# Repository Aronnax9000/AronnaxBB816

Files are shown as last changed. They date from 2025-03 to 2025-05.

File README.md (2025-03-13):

# AronnaxBB816
Memory Board
16777216 bytes = 16 MB = 0x1000000
65536 bytes = 64 KB 0x10000 (0x0000 - 0xFFFF)
There are sixteen 64 KB banks in a megabyte.
2^20 1 megabyte 0x100000 

0x000000-0x07FFFF Low  512 KB RAM
0x080000-0x0FFFFF High 512 KB RAM
0x000100-0x0001FF Bank 0 Page 1 I/O
                  VIA 0 (16 bytes)
                  VIA 1 (16 bytes)
                  ACIA (4 bytes)
                  
0x008000-0x00FFFF EEPROM (read when E signal is active)
                  RAM (write always on ~WR, read when E signal is not active)

Board uses A0-A19 (20 lines). 

Active when MEG0 = ~A23 * ~A22 * ~A21 * ~A20.
MEG0_UPPER = MEG0 * A19
MEG0_LOWER = MEG0 * ~A19

~BANK0_UPPER = ~BANK0 + ~A15
~BANK0_LOWER = ~BANK0 + A15

~EEPROM_CS = ~E + ~BANK0_UPPER

I/O Active when BANK0_LOWER * A8 * ~A9 * ~A10 * ~A11 * ~A12 * ~A13 * ~A14

Vector Pull Rewrite

2.28 Vector Pull (VPB)

The Vector Pull active low output indicates that a vector location is being addressed during an interrupt
sequence. VPB is low during the last two interrupt sequence cycles, during which time the processor loads
the PC with the interrupt handler vector location. The VPB signal may be used to select and prioritize
interrupts from several sources by modifying the vector addresses.

Table 5-2 Emulation Mode Vector Locations (8-bit Mode)

|Address | Label | Function | 
00FFFE,F | IRQB/BRK | Hardware/Software | 
00FFFC,D | RESETB | Hardware | 
00FFFA,B | NMIB | Hardware | 
00FFF8,9 | ABORTB | | Hardware | 
00FFF6,7 | (Reserved) | Hardware | 
00FFF4,5 | COP | Software | 
00FFF2,3 | (Reserved) | 
00FFF0,1 | (Reserved) | 

Table 5-3 Native Mode Vector Locations (16-bit Mode)

Address | Label | Function | 
00FFEE,F | IRQB | Hardware | 
00FFEC,D | (Reserved) | 
00FFEA,B | NMIB | Hardware | 
00FFE8,9 | ABORTB| | 
00FFE6,7 | BRK | Software | 
00FFE4,5 | COP | Software| 
00FFE2,3 | (Reserved) | |
00FFE0,1 | (Reserved) | |

The VP output is low during the two cycles used for vector location access. When an interrupt is executed,
D=0 and I=1 in Status Register P.

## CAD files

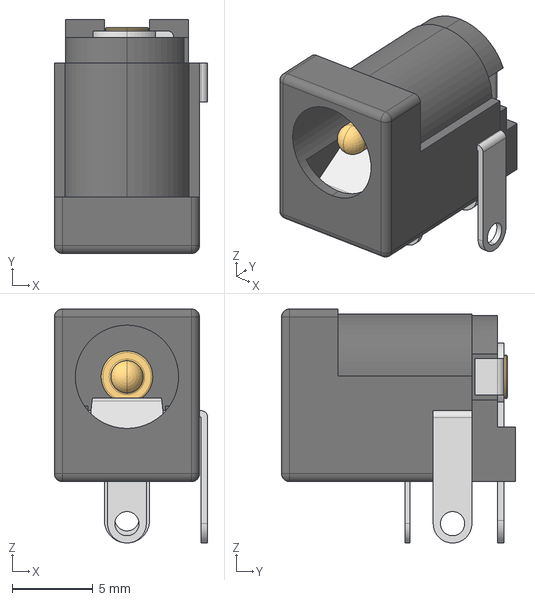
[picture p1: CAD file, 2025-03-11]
AronnaxMemory/3dmodels/163-179PH-EX.stp
9.50 x 14.5 x 14.5 mm

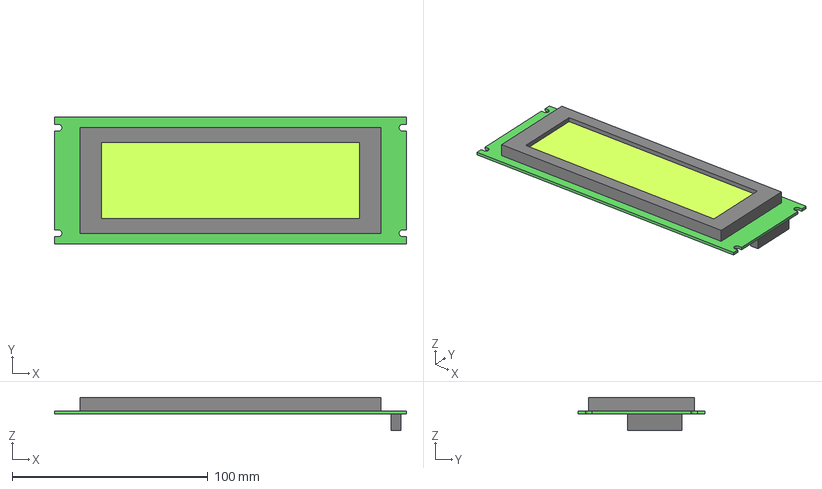
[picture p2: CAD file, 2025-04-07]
AronnaxMemory/3dmodels/lcd24064.step
180.0 x 65.0 x 17.1 mm
PCBBody
ConnBody
Matrix
Display

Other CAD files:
AronnaxMemory/3dmodels/lcd24064.FCStd
AronnaxMemory/3dmodels/lcd24064.stl

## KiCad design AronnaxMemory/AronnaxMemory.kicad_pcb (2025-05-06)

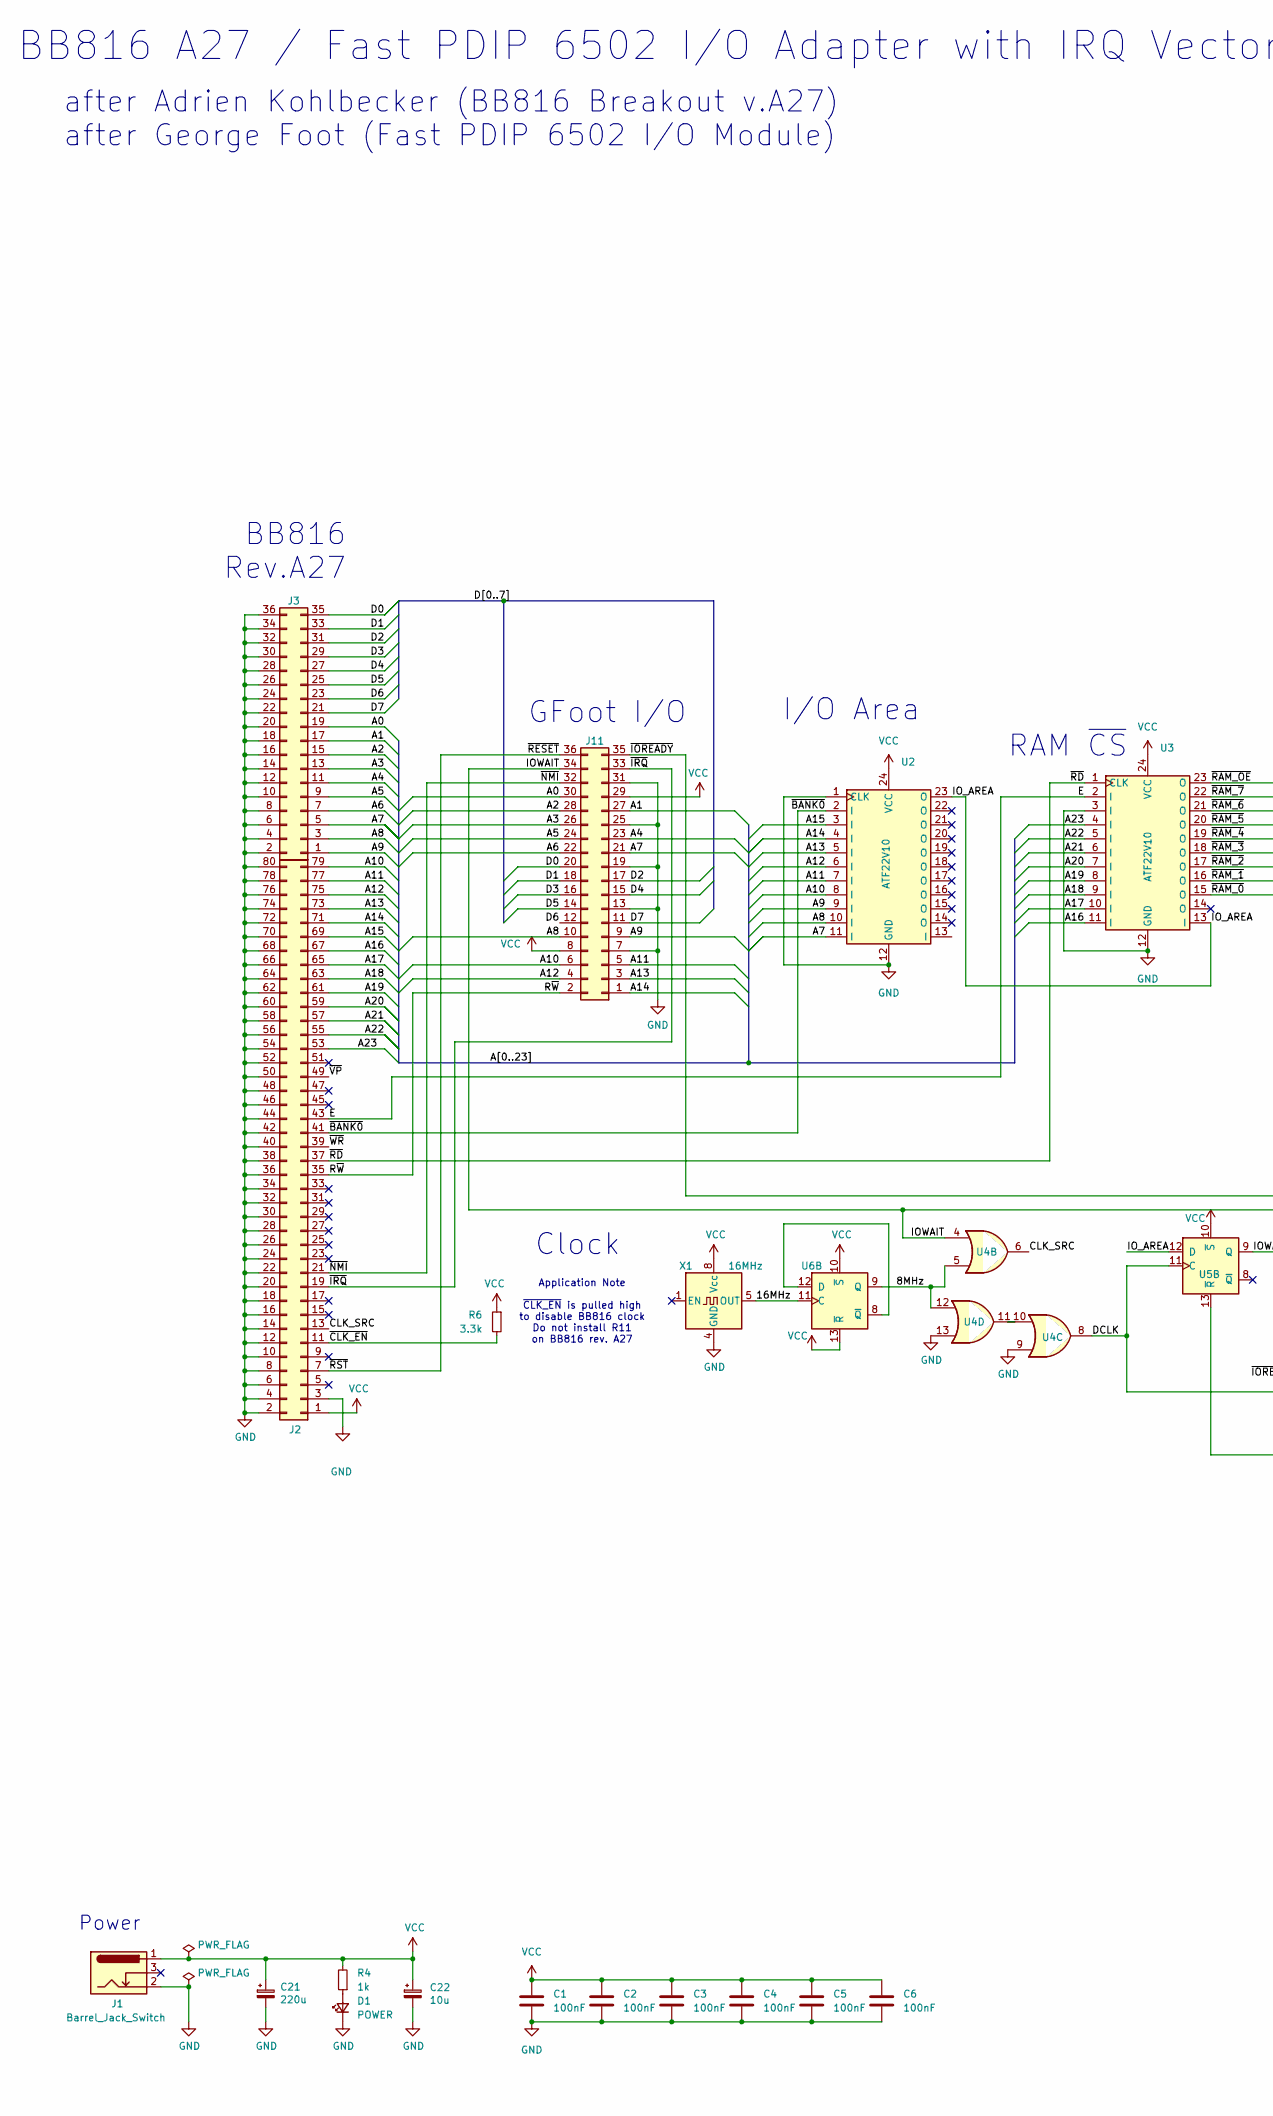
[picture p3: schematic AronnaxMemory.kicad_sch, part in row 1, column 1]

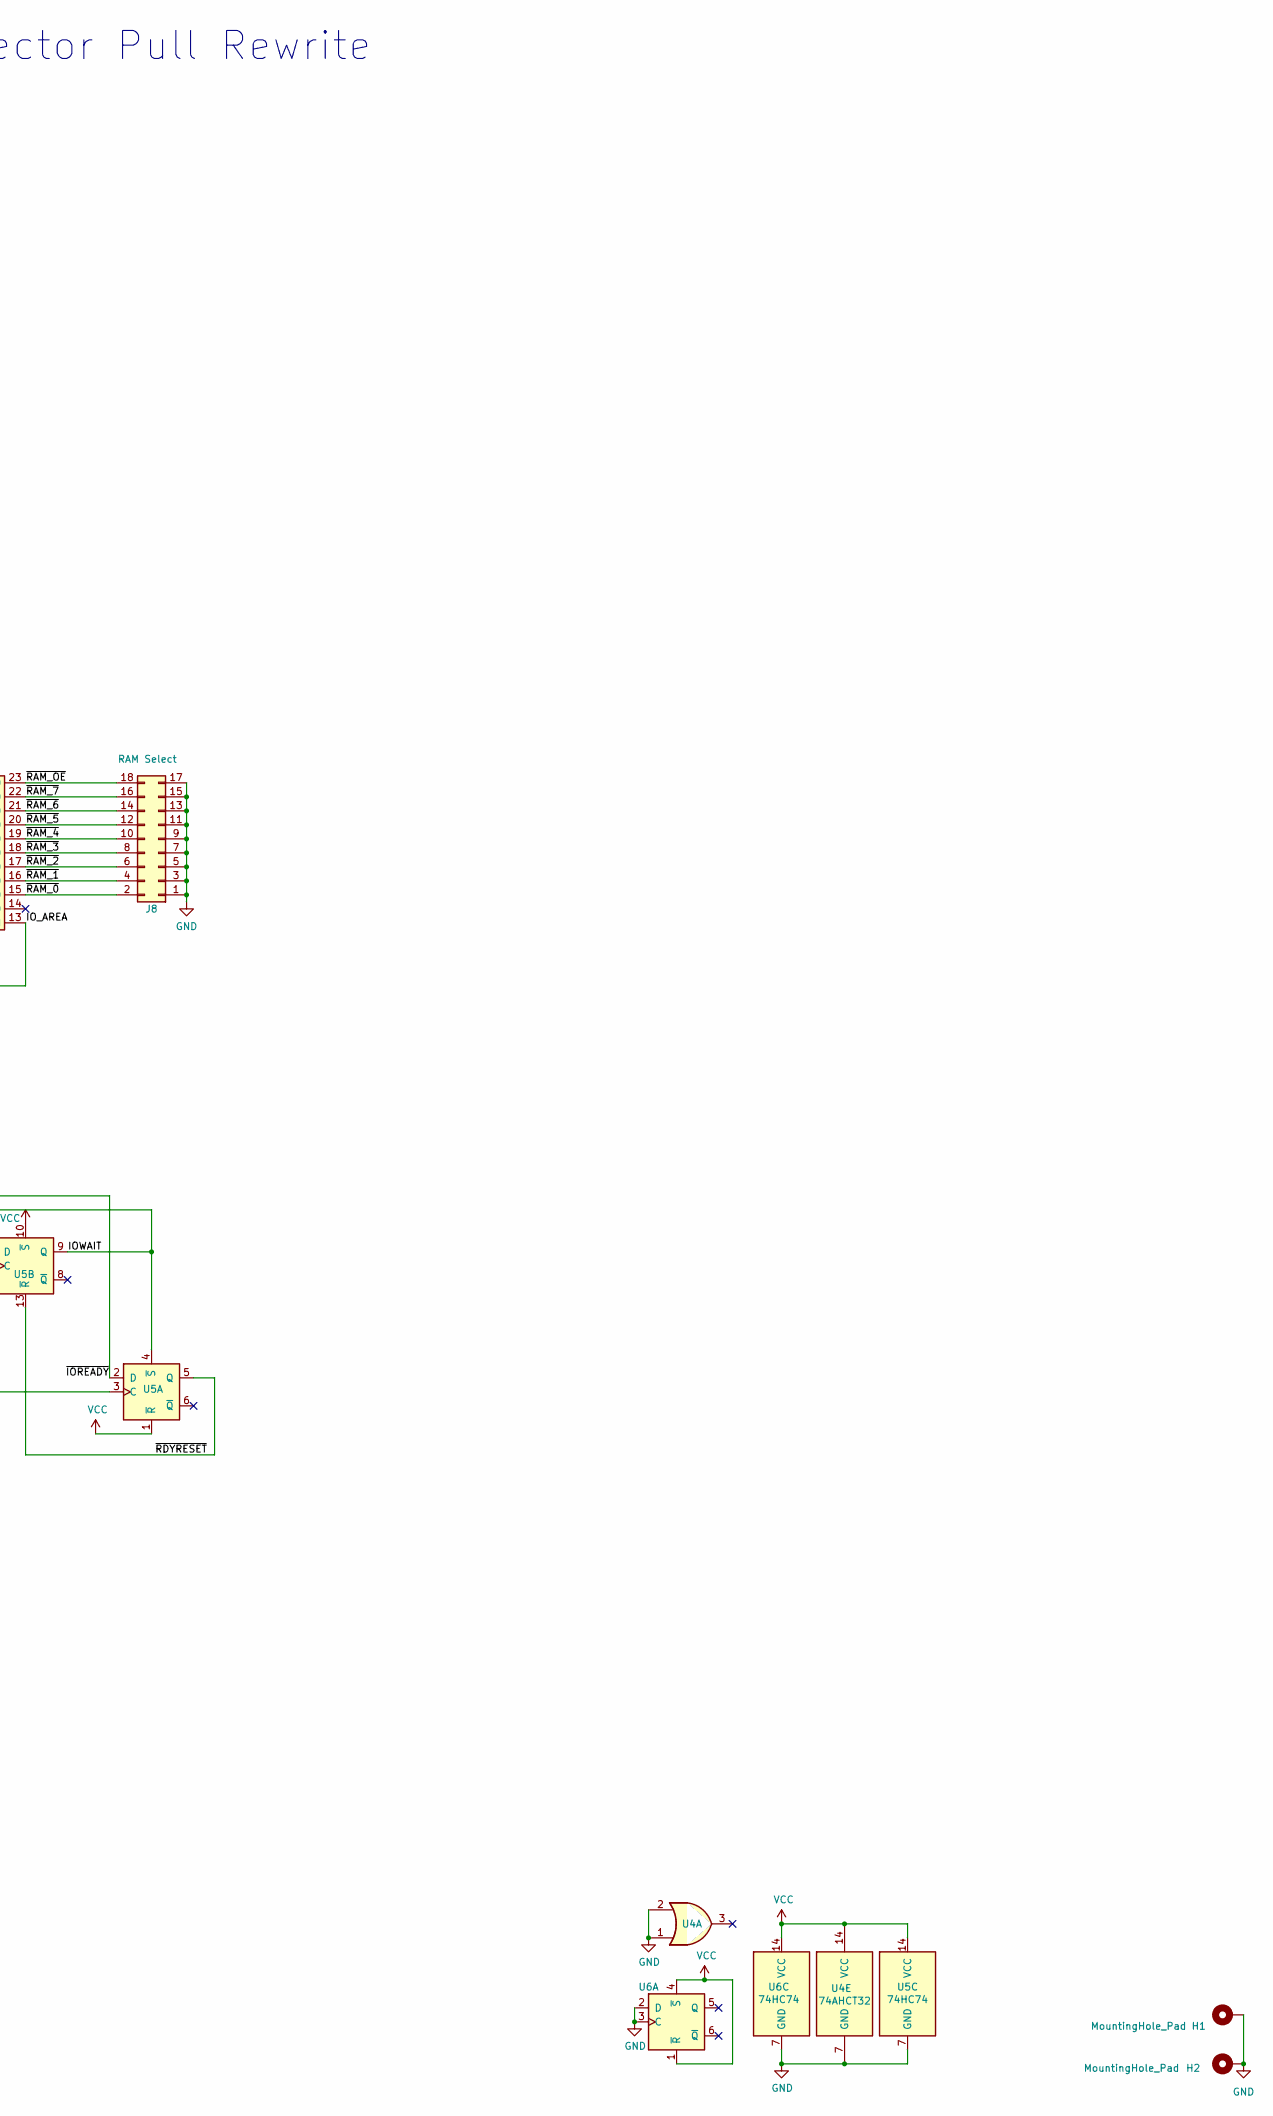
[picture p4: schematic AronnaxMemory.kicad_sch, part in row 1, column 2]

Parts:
C1, C2, C3, C4, C5, C6: 100nF; C_Disc_D3.4mm_W2.1mm_P2.50mm
C21: 220u; CP_Radial_D6.3mm_P2.50mm
C22: 10u; CP_Radial_D4.0mm_P1.50mm
D1: POWER; LED_D3.0mm
H1, H2: MountingHole_Pad; MountingHole_3.2mm_M3_Pad
J1: Barrel_Jack_Switch; BarrelJack_Horizontal
J2: Conn_02x40_Odd_Even; PinHeader_2x40_P2.54mm_Vertical
J3: Conn_02x18_Odd_Even; PinHeader_2x18_P2.54mm_Vertical
J8: RAM Select; PinHeader_2x09_P2.54mm_Vertical
J11: Conn_02x18_Odd_Even; PCB_Edge_36pin
R4: 1k; R_Axial_DIN0207_L6.3mm_D2.5mm_P7.62mm_Horizontal
R6: 3.3k; R_Axial_DIN0207_L6.3mm_D2.5mm_P7.62mm_Horizontal
U2, U3: ATF22V10; DIP-24_W7.62mm_Socket
U4: 74AHCT32; DIP-14_W7.62mm_Socket
U5, U6: 74HC74; DIP-14_W7.62mm_Socket
X1: 16MHz; Oscillator_DIP-8

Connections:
/8MHz: U4.5, U4.12, U6.9 (Q)
/16MHz: U6.11 (C), X1.5 (OUT)
/A0: J3.19, J11.30
/A1: J3.17, J11.27
/A2: J3.15, J11.28
/A3: J3.13, J11.26
/A4: J3.11, J11.23
/A5: J3.9, J11.24
/A6: J3.7, J11.22
/A7: J3.5, J11.21, U2.11 (I)
/A8: J3.3, J11.10, U2.10 (I)
/A9: J3.1, J11.9, U2.9 (I)
/A10: J2.79, J11.6, U2.8 (I)
/A11: J2.77, J11.5, U2.7 (I)
/A12: J2.75, J11.4, U2.6 (I)
/A13: J2.73, J11.3, U2.5 (I)
/A14: J2.71, J11.1, U2.4 (I)
/A15: J2.69, U2.3 (I)
/A16: J2.67, U3.11 (I)
/A17: J2.65, U3.10 (I)
/A18: J2.63, U3.9 (I)
/A19: J2.61, U3.8 (I)
/A20: J2.59, U3.7 (I)
/A21: J2.57, U3.6 (I)
/A22: J2.55, U3.5 (I)
/A23: J2.53, U3.4 (I)
/CLK_SRC: J2.13, U4.6
/D0: J3.35, J11.20
/D1: J3.33, J11.18
/D2: J3.31, J11.17
/D3: J3.29, J11.16
/D4: J3.27, J11.15
/D5: J3.25, J11.14
/D6: J3.23, J11.12
/D7: J3.21, J11.11
/DCLK: U4.8, U5.3 (C), U5.11 (C)
/E: J2.43, U3.2 (I)
/IOWAIT: J11.34, U4.4, U5.4 (~S), U5.9 (Q)
/IO_AREA: U2.23 (O), U3.13 (I), U5.12 (D)
/R~W: J2.35, J11.2
/~BANK0: J2.41, U2.2 (I)
/~CLK_EN: J2.11, R6.2
/~IOREADY: J11.35, U5.2 (D)
/~IRQ: J2.19, J11.33
/~NMI: J2.21, J11.32
/~RAM_0: J8.2, U3.15 (O)
/~RAM_1: J8.4, U3.16 (O)
/~RAM_2: J8.6, U3.17 (O)
/~RAM_3: J8.8, U3.18 (O)
/~RAM_4: J8.10, U3.19 (O)
/~RAM_5: J8.12, U3.20 (O)
/~RAM_6: J8.14, U3.21 (O)
/~RAM_7: J8.16, U3.22 (O)
/~RAM_OE: J8.18, U3.23 (O)
/~RDYRESET: U5.5 (Q), U5.13 (~R)
/~RD: J2.37, U3.1 (CLK)
/~RESET: J2.7, J11.36
/~VP: J2.49
/~WR: J2.39
GND: C1.2, C2.2, C3.2, C4.2, C5.2, C6.2, C21.2, C22.2, D1.1 (K), H1.1, H2.1, J1.2, J2.2, J2.3, J2.4, J2.6, J2.8, J2.10, J2.12, J2.14, J2.16, J2.18, J2.20, J2.22, J2.24, J2.26, J2.28, J2.30, J2.32, J2.34, J2.36, J2.38, J2.40, J2.42, J2.44, J2.46, J2.48, J2.50, J2.52, J2.54, J2.56, J2.58, J2.60, J2.62, J2.64, J2.66, J2.68, J2.70, J2.72, J2.74, J2.76, J2.78, J2.80, J3.2, J3.4, J3.6, J3.8, J3.10, J3.12, J3.14, J3.16, J3.18, J3.20, J3.22, J3.24, J3.26, J3.28, J3.30, J3.32, J3.34, J3.36, J8.1, J8.3, J8.5, J8.7, J8.9, J8.11, J8.13, J8.15, J8.17, J11.7, J11.13, J11.19, J11.25, J11.31, U2.1 (CLK), U2.12 (GND), U3.3 (I), U3.12 (GND), U4.1, U4.2, U4.7 (GND), U4.9, U4.13, U5.7 (GND), U6.2 (D), U6.3 (C), U6.7 (GND), X1.4 (GND)
unnamed: D1.2 (A), R4.1
unnamed: U4.10, U4.11
unnamed: U6.8 (~Q), U6.12 (D)
VCC: C1.1, C2.1, C3.1, C4.1, C5.1, C6.1, C21.1, C22.1, J1.1, J2.1, J11.8, J11.29, R4.2, R6.1, U2.24 (VCC), U3.24 (VCC), U4.14 (VCC), U5.1 (~R), U5.10 (~S), U5.14 (VCC), U6.1 (~R), U6.4 (~S), U6.10 (~S), U6.13 (~R), U6.14 (VCC), X1.8 (Vcc)

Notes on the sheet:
RAM ~{CS}
Power
GFoot I/O
BB816 Rev.A27
after Adrien Kohlbecker (BB816 Breakout v.A27) after George Foot (Fast PDIP 6502 I/O Module)
Clock
I/O Area
BB816 A27 / Fast PDIP 6502 I/O Adapter with IRQ Vector Pull Rewrite
Application Note ~{CLK_EN} is pulled high to disable BB816 clock Do not install R11 on BB816 rev. A27

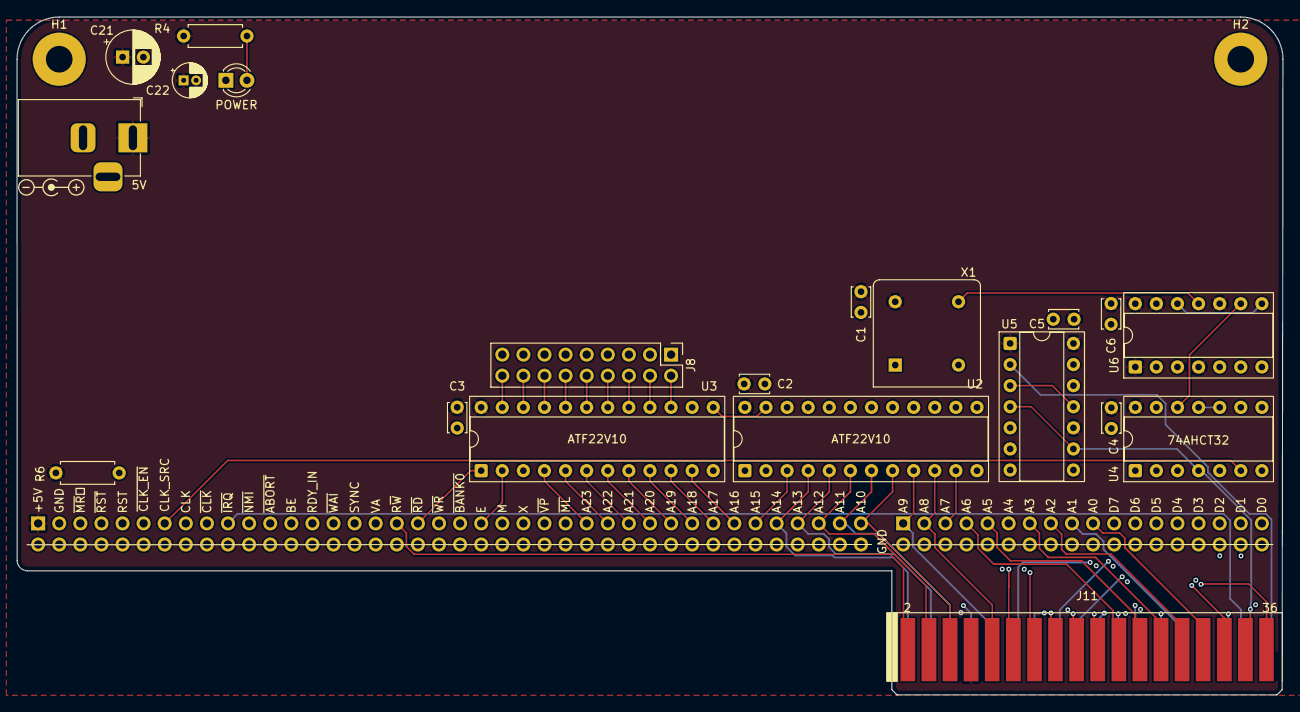
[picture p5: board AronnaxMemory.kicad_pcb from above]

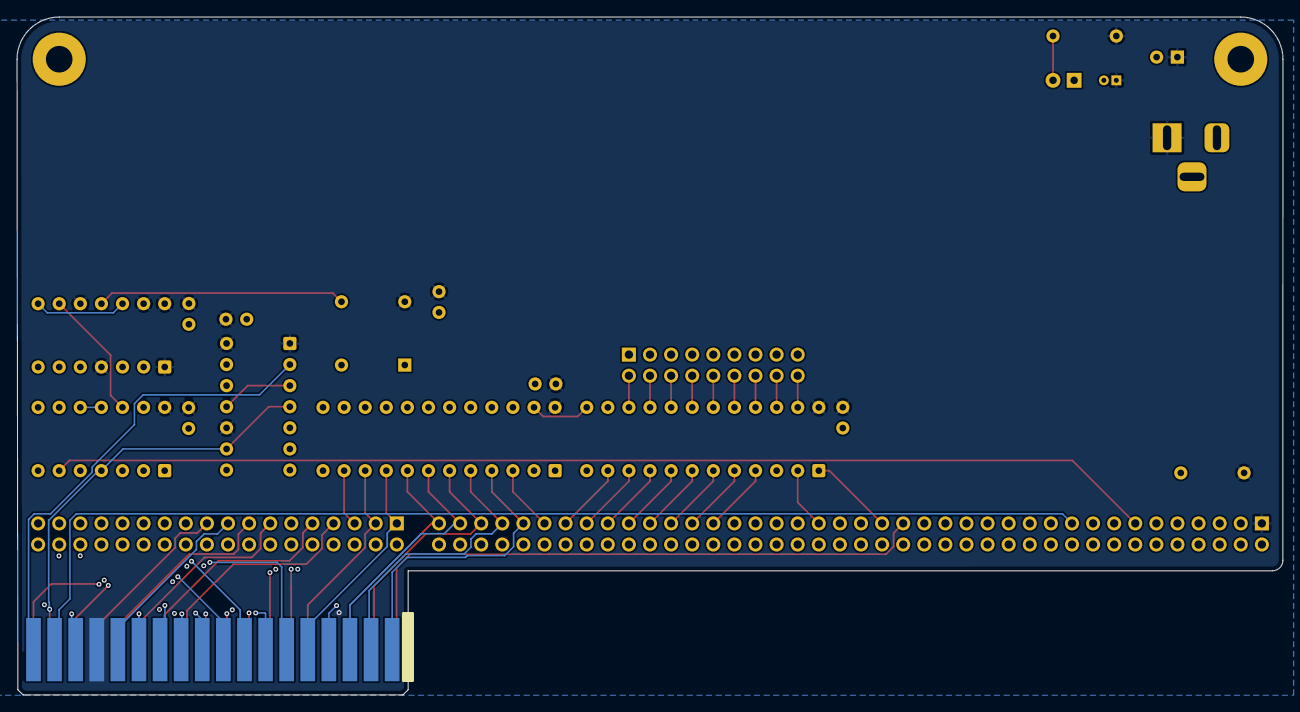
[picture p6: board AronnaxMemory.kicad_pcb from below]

Board: 6 copper layers, 152.4 x 81.6 mm, 24 parts (2 on the bottom side), 62 nets.

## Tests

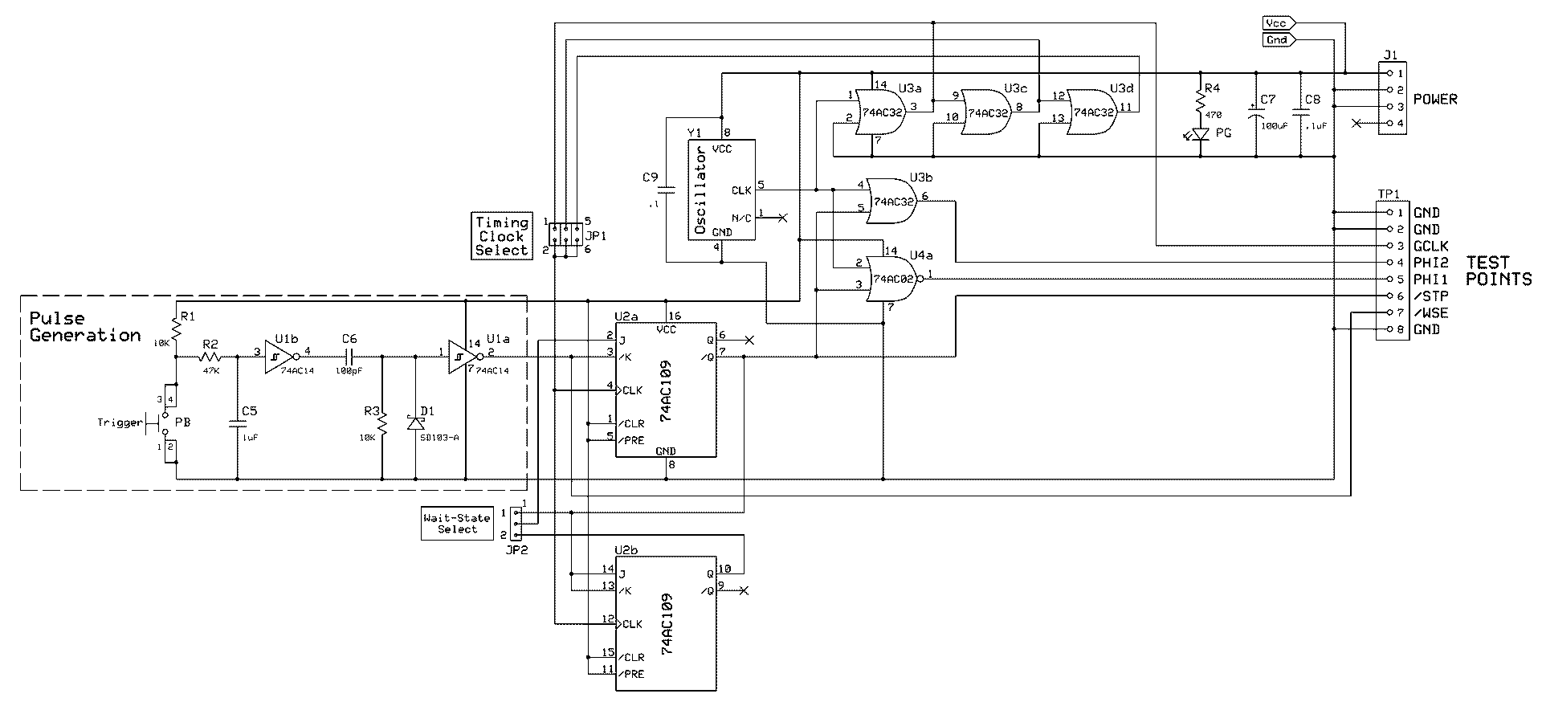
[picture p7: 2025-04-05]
datasheets/wait_state_test_v2.gif

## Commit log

2025-03-11 Add original Kohlbecker snapshot.
    [BAR-10-BRYG.step, BAR-8-RYG.step, BB816.kicad_pcb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]
2025-03-11 Resaved all Kohlbecker files in Kicad 9
    [BB816.kicad_pcb, BB816.kicad_sch, address_decoding.kicad_sch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]
2025-03-11 First big Aronnax push.
    [AronnaxMemory.kicad_pcb, AronnaxMemory.kicad_sch, ramrom.kicad_sch]
2025-03-11 Before deleting high memory
    [AronnaxMemory.kicad_pcb, AronnaxMemory.kicad_sch]
2025-03-11 Ready update schematic with added components to breakout
    [AronnaxMemory.kicad_pcb, AronnaxMemory.kicad_sch, breakout.kicad_sch]
2025-03-11 Before PCB update
    [breakout.kicad_sch]
2025-03-11 More preening.
    [breakout.kicad_sch]
2025-03-13 New pcb
    [breakout.kicad_pcb, breakout.kicad_sch]
2025-03-13 All of it.
    [breakout.kicad.kicad_sch, breakout.kicad.sch, breakout_bare.kicad_pcb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]
2025-03-17 getting ready to add VPB rewrite
    [AronnaxMemory.kicad_pcb, AronnaxMemory2.kicad_pcb]
2025-04-03 PLAs for Days! Also Vector Rewrite
    [AronnaxMemory.kicad_pcb, AronnaxMemory.kicad_sch]
2025-04-04 Heal board
    [AronnaxMemory.kicad_pcb, AronnaxMemory.kicad_sch]
2025-04-05 Everything, except the plot.
    [AronnaxMemory.kicad_pcb, AronnaxMemory.kicad_sch]
2025-04-07 Refactor project.
    [163-179PH-EX.stp, ACIA0.kicad_sch, ACIA1.kicad_sch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]
2025-04-15 All of it
    [AronnaxMemory.kicad_pcb, AronnaxMemory.kicad_sch, Clock.kicad_sch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]
2025-04-15 All of it p2
    [AronnaxMemory.kicad_pcb, AronnaxMemory.kicad_sch, Clock.kicad_sch]
2025-04-15 All of it v3
    [AronnaxIO.kicad_pcb, AronnaxIO.kicad_sch]
2025-04-16 Before replacing 22V10 with 4 bit adder
    [AronnaxMemory.kicad_pcb, AronnaxMemory.kicad_sch]
2025-04-17 Gettin ready to publish
    [AronnaxMemory.kicad_pcb, AronnaxMemory.kicad_sch]
2025-04-17 Simplifying Removed VPR
    [AronnaxMemory.kicad_pcb, AronnaxMemory.kicad_sch]
2025-05-06 May 2025
    [AronnaxMemory.kicad_pcb, AronnaxMemory.kicad_sch, IRQRewrite.kicad_sch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]

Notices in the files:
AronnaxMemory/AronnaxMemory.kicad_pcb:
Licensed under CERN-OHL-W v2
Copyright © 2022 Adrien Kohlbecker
